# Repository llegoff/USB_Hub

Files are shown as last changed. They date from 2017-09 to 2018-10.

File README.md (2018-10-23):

[:fr:](LISEZMOI.md) [:uk:](README.md)

# USB_Hub
GL852G or GL850G usb2.0 hub PiZero format

GL852G is Multi TT hub chip

GL850G is Single TT hub chip

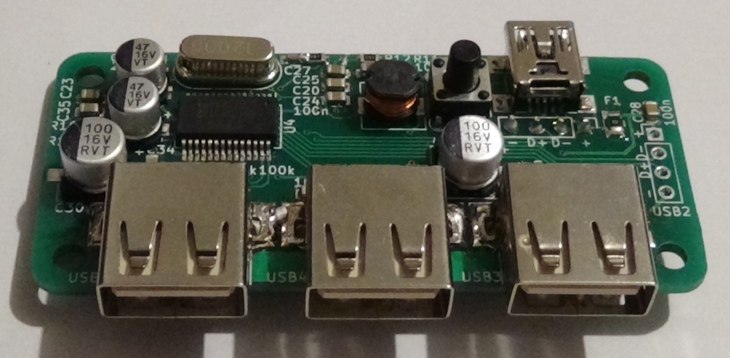
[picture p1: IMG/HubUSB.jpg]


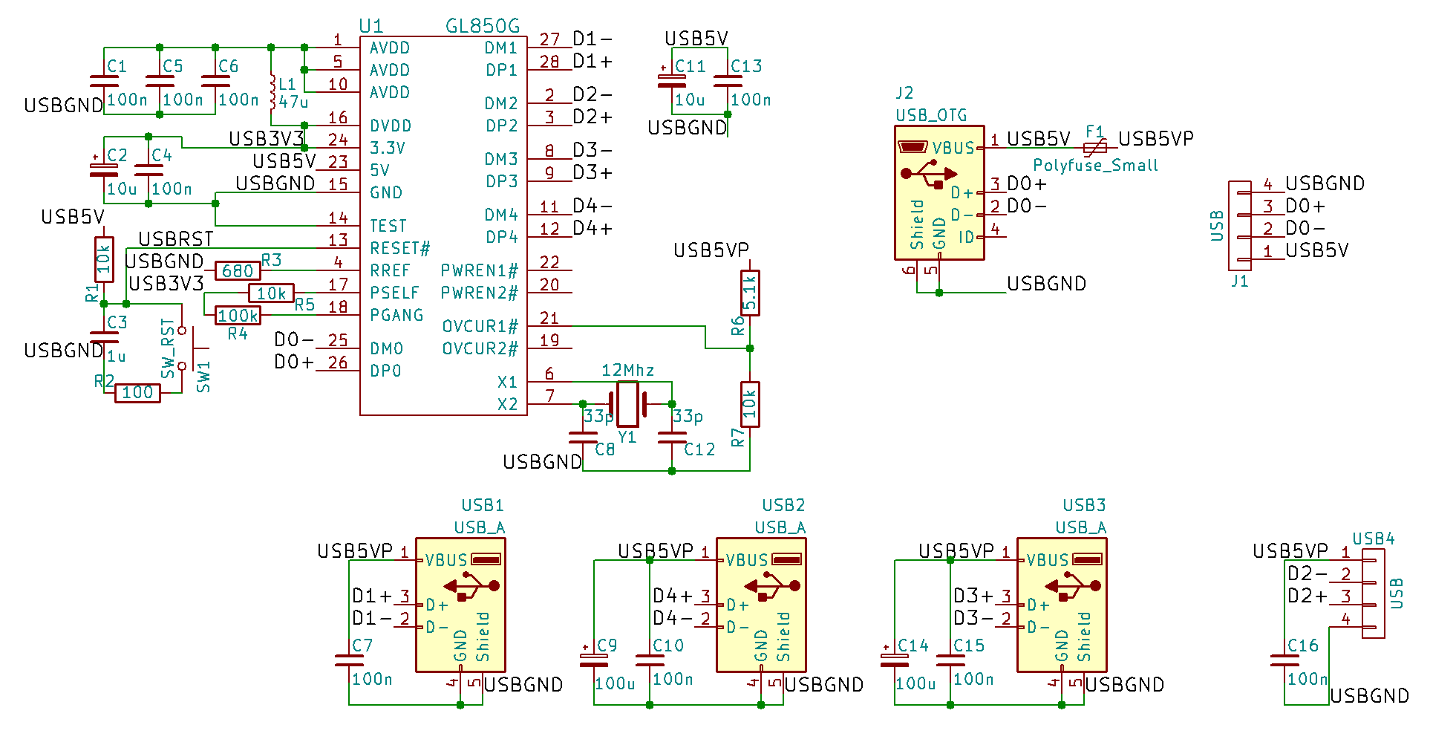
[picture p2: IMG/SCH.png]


rev1
- R12 (new R3 in rev2) is connected to 5v, it must be connected to gnd
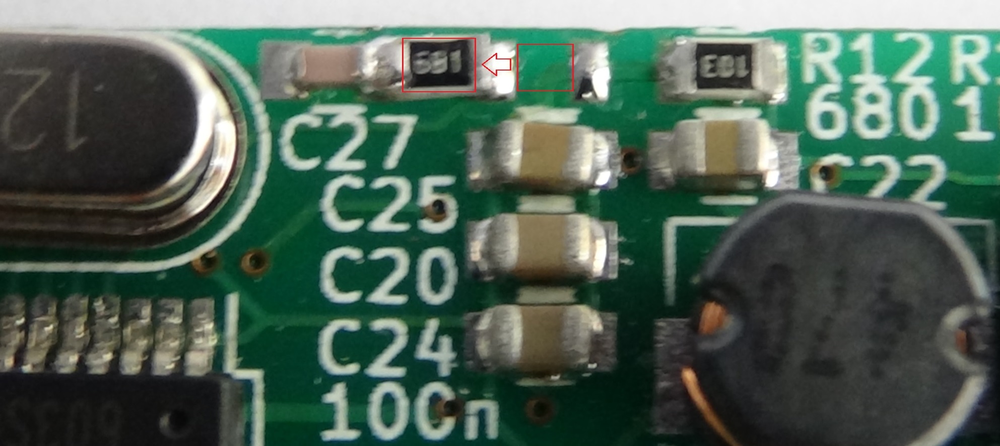
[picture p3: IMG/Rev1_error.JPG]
rev1 error


rev2
- Change R3 route
- Change the numbering of the components

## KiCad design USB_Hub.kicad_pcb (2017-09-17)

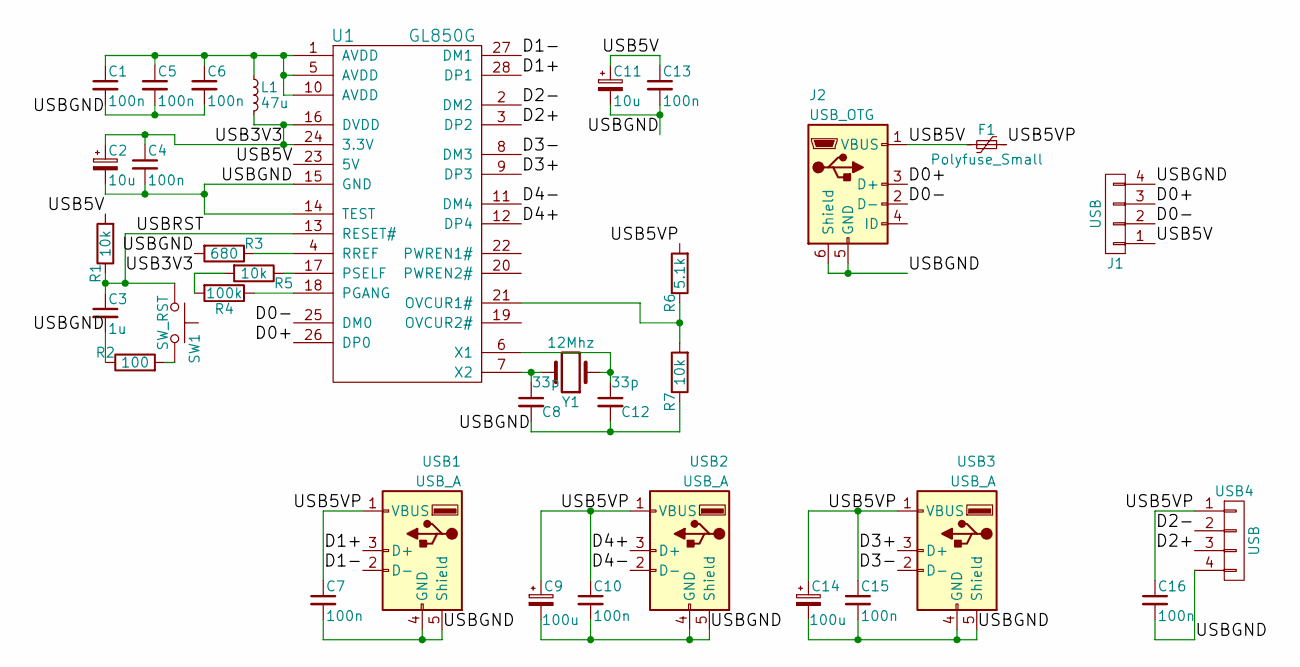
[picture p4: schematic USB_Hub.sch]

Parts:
C1, C4, C5, C6, C7, C10, C13, C15, C16: 100n; C_0805
C2, C11: 10u; CP_Elec_4x5.7
C3: 1u; C_0805
C8, C12: 33p; C_0805
C9, C14: 100u; CP_Elec_6.3x5.3
F1: Polyfuse_Small; Fuse_SMD1206_Reflow
J1: USB; Pin_Header_Straight_1x04_Pitch2.54mm
J2: USB_OTG; USB_Mini-B
L1: 47u; L_6.3x6.3_H3
R1, R5, R7: 10k; R_0805
R2: 100; R_0805
R3: 680; R_0805
R4: 100k; R_0805
R6: 5.1k; R_0805
SW1: SW_RST; SW_PUSH_6mm
U1: GL850G; SSOP-28_5.3x10.2mm_Pitch0.65mm
USB1, USB2, USB3: USB_A; USB_A_TTH&SMD
USB4: USB; Pin_Header_Straight_1x04_Pitch2.54mm
Y1: 12Mhz; Crystal_HC49-U_Vertical

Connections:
/D0+: J1.3, J2.3 (D+), U1.26 (DP0)
/D0-: J1.2, J2.2 (D-), U1.25 (DM0)
/D1+: U1.28 (DP1), USB1.3 (D+)
/D1-: U1.27 (DM1), USB1.2 (D-)
/D2+: U1.3 (DP2), USB4.3
/D2-: U1.2 (DM2), USB4.2
/D3+: U1.9 (DP3), USB3.3 (D+)
/D3-: U1.8 (DM3), USB3.2 (D-)
/D4+: U1.12 (DP4), USB2.3 (D+)
/D4-: U1.11 (DM4), USB2.2 (D-)
/USB3V3: C2.1, C4.1, L1.2, R4.2, R5.2, U1.16 (DVDD), U1.24 (3.3V)
/USB5V: C11.1, C13.1, F1.2, J1.1, J2.1 (VBUS), R1.2, U1.23 (5V)
/USB5VP: C7.1, C9.1, C10.1, C14.1, C15.1, C16.1, F1.1, R6.2, USB1.1 (VBUS), USB2.1 (VBUS), USB3.1 (VBUS), USB4.1
/USBGND: C1.2, C2.2, C3.2, C4.2, C5.2, C6.2, C7.2, C8.2, C9.2, C10.2, C11.2, C12.2, C13.2, C14.2, C15.2, C16.2, J1.4, J2.5 (GND), J2.6 (Shield), R2.1, R3.2, R7.1, U1.14 (TEST), U1.15 (GND), USB1.4 (GND), USB1.5 (Shield), USB2.4 (GND), USB2.5 (Shield), USB3.4 (GND), USB3.5 (Shield), USB4.4
/USBRST: C3.1, R1.1, SW1.1, U1.13 (RESET#)
unnamed: C1.1, C5.1, C6.1, L1.1, U1.1 (AVDD), U1.5 (AVDD), U1.10 (AVDD)
unnamed: C8.1, U1.7 (X2), Y1.2
unnamed: C12.1, U1.6 (X1), Y1.1
unnamed: R2.2, SW1.2
unnamed: R3.1, U1.4 (RREF)
unnamed: R4.1, U1.18 (PGANG)
unnamed: R5.1, U1.17 (PSELF)
unnamed: R6.1, R7.2, U1.21 (OVCUR1#)

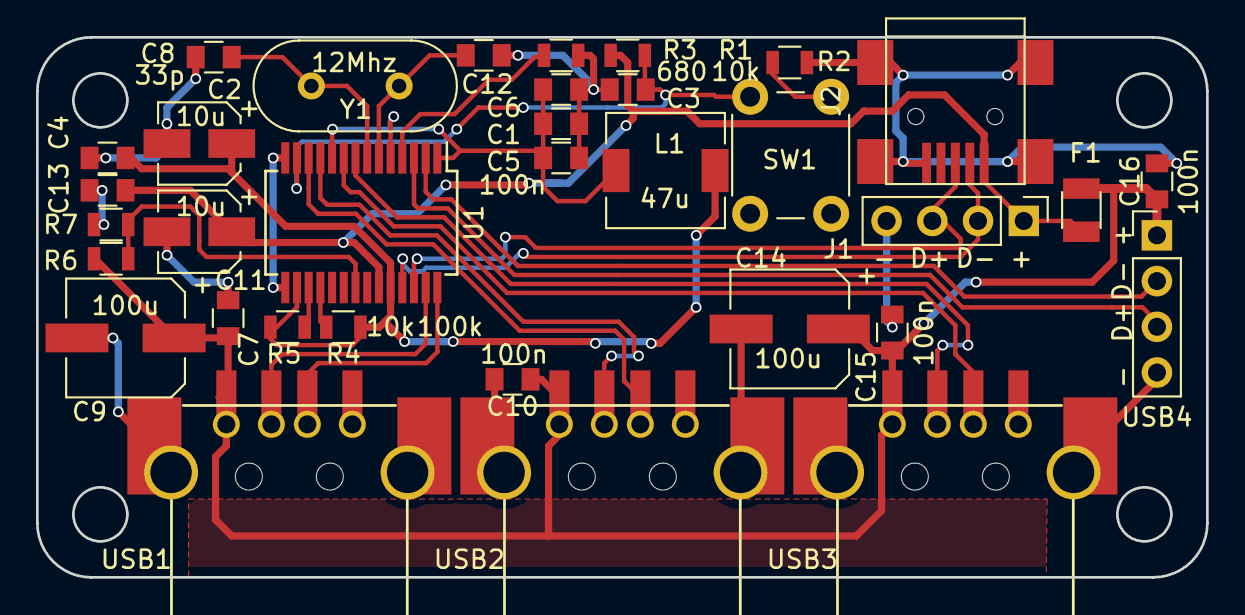
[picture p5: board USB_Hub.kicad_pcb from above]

Board: 2 copper layers, 65.0 x 30.0 mm, 34 parts (0 on the bottom side), 23 nets.
